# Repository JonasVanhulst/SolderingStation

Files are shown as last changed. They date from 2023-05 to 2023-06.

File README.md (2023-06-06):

# Hello, i am Jonas Vanhulst 👋

As first year electronics ICT engineer, i am very happy that i could make this nice and working soldering station.

## issues ✍️
By testing the result i found a problem while powering the opamp. The opamp didn't receive the 5V so i checked the PCB design and i found a problem with connecting the 5V to the Opamp.
So for solving this problem a singel wire was placed between the opamp and a 5V pin.

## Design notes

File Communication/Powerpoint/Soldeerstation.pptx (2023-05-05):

## Technisch ontwerp

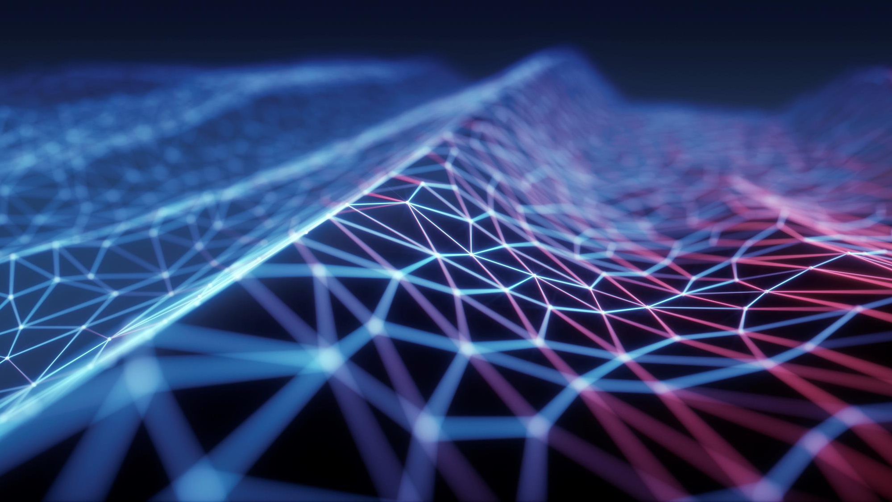
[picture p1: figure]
Digitale verbindingen

## Technische benodigdheden

SOFTWARE
COMPONENTEN
GITHUB

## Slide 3

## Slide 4

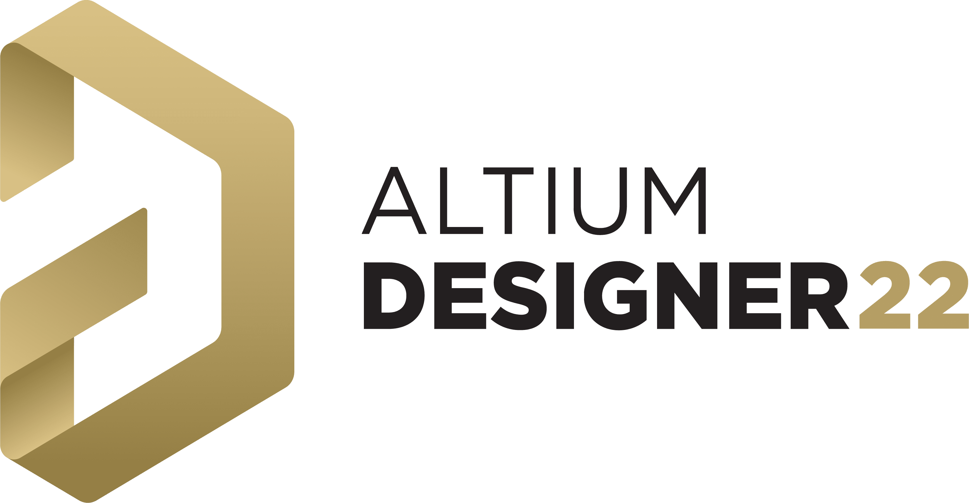
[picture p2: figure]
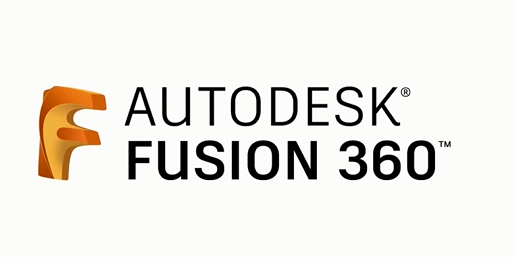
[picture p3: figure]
Fusion 360 der Einstieg – drucktipps3d.de

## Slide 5

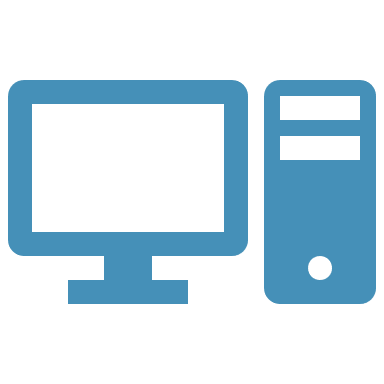
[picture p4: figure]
Computer

SOFTWARE

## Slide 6

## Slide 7

## Concurrerend landschap

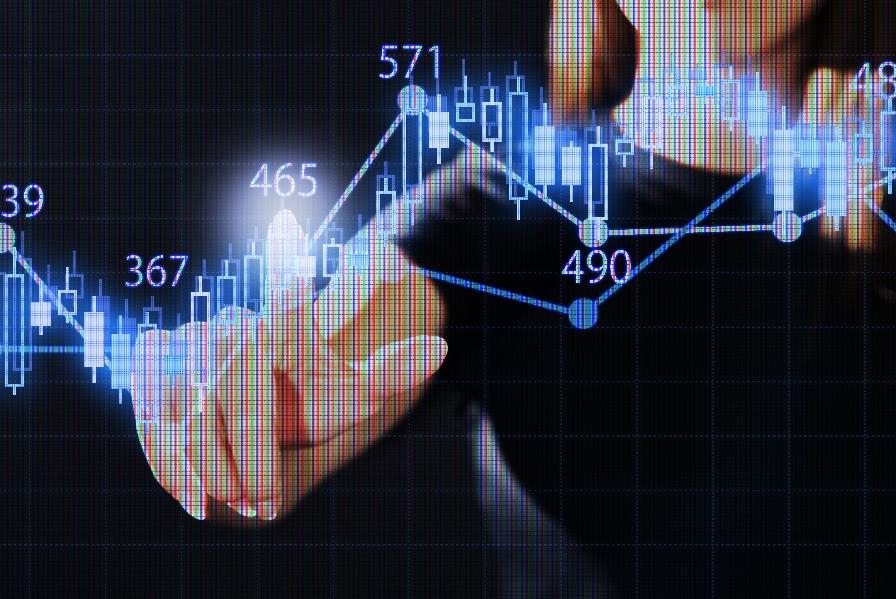
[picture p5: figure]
Grafieken
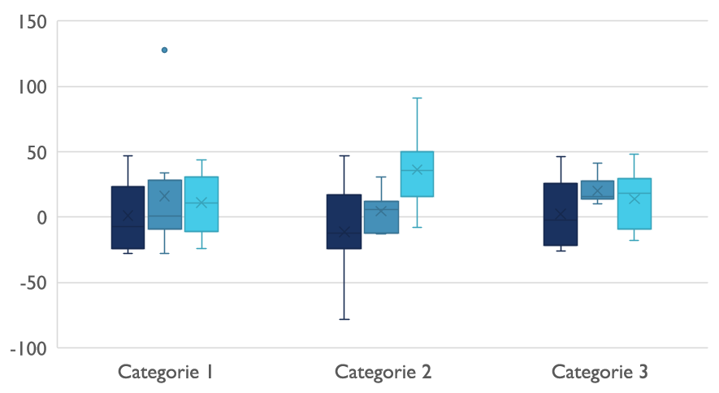
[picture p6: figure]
Tijdelijke aanduiding voor grafiek

## Digitale communicatie

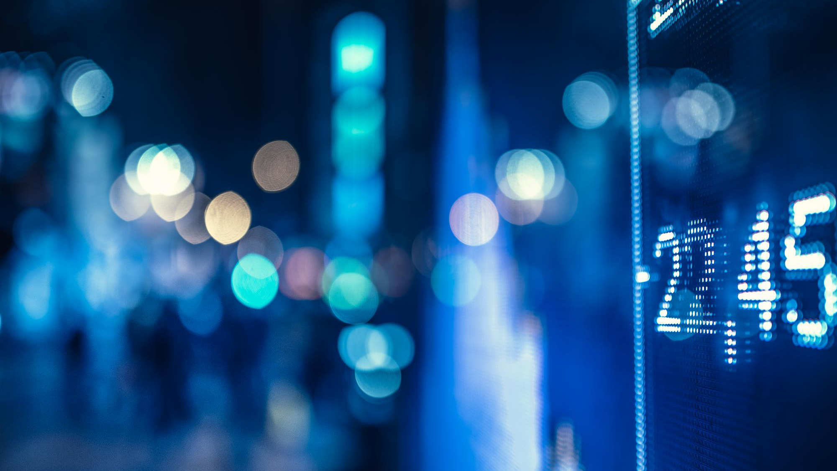
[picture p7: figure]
Digitale cijfers

Cloud
Lokaal
Hybride

## Bedankt

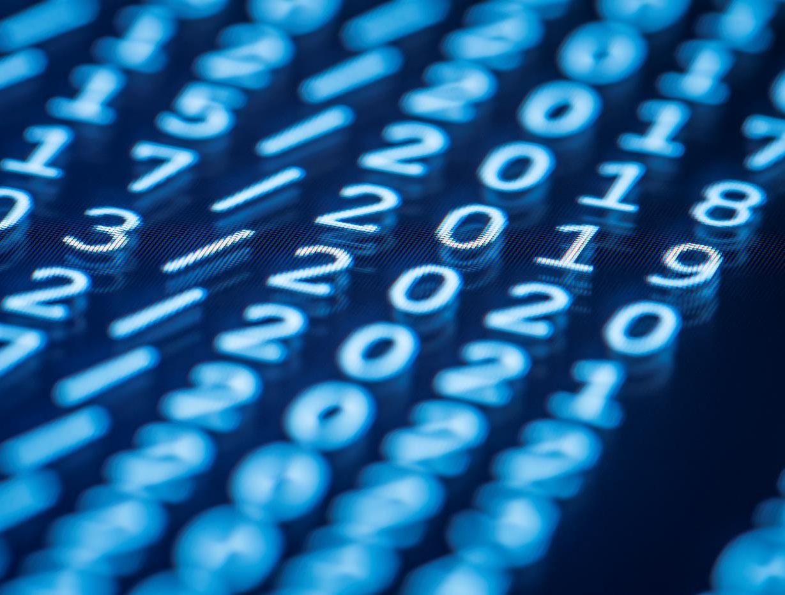
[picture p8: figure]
Digitale cijfers

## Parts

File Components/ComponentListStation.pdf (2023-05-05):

Description | Supplier

Resistor
18 kΩ | provided by PXL
1 MΩ | provided by PXL
68 kΩ | provided by PXL
5.6 kΩ, | provided by PXL
10 kΩ | provided by PXL
100 Ω | provided by PXL
10 MΩ | provided by PXL
4.7 kΩ | provided by PXL
470 Ω | provided by PXL
Inductor
Choke 10uH, 130mA | Gotron
Common mode choke 10A, Laird CM2545x171B-10 | Farnell
Capacitor
4700 µF, 50 V | Farnell
10 µF, 50 V | In stock at home
100 nF, 50 V | provided by PXL
100 µF, 50 V | Farnell
10nF, 50V | provided by PXL
Semiconductor
1N4007, 1000 V | In stock at home
Zener Single Diode, 5.1 V, 500 mW | Farnell
1N4148, 100 V, 200 mA | Farnell
Bridge rectifier D6KB6U, 600V, 6A | Farnell
BC547C, 45 V, 100 mA, 500 mW, hfe=400 | In stock at home
IRF9Z34NPBF, MOSFET-P, 55V, 17A, 100mOhm | Farnell
BC557C, -45 V, -100 mA, 500 mW, hfe=400 | In stock at home
DC/DC converter OKI-78SR-5/1.5-W36-C, 5V, 1.5A | RS components
Dual OPAMP MCP6002-E/P | Farnell
8-bit MCU ATmega4809-PF | Farnell
Other
Power Relay, 5 VDC, DPDT, 8A, Schrack RT424005 | Farnell
Terminal block | In stock at home
Pin header | provided by PXL
Pin header | provided by PXL
Pin header | provided by PXL
Pin header | provided by PXL
Pin header | provided by PXL
8 pin dip socket | In stock at home
20 pin dip socket | Gotron
40 pin dip socket | Gotron
10-way boxheader | Farnell
10 pin connector | provided by PXL
Misc.
Toroidal mains transformer 60VA, 2x115V, 2x12V, MCTA060/12 | TME
primary fuse 20mm 630mA @240VAC | Farnell
IEC connector | Amazon

## BOM:Soldering Station

10-way IDC Receptable | Fanell
10-aderige flatcable | Gotron
Encoder with pushbutton, Bourns PEC11R-4225F-N0024 | Farnell
Display
4 digit 7-segment LED display KW4-801AVB | TME
I2C LED drive control special circuit TM1637 | Amazon

Reference | Qnt | Delivery date
253 | Always available 1 | Always available 1 | Always available 4 | Always available 6 | Always available 2 | Always available 1 | Always available 6 | Always available 1 | Always available 2

78F100J-RC
1 | | | | | | | | | | | next day
CM2545X171B-10
1 | | | | | | | | | | | 19/03/2023
17
MCGPR50V478M22X41
1 | | | | | | | | | | | 19/03/2023
MCGPR50V106M5X11
3 | | | | | | | | | | | Always available
MCRR50104X7RK0050
6 | | | | | | | | | | | Always available
MCGPR50V107M8X11
2 | | | | | | | | | | | 19/03/2023
SR215C103KAR
5 | | | | | | | | | | | Always available
13
1N4007
1 | | | | | | | | | | | Always available
1N5231B+
1 | | | | | | | | | | | 19/03/2023
1N4148T
1 | | | | | | | | | | | 19/03/2023
D6KB6U
2 | | | | | | | | | | | 19/03/2023
BC547CG
3 | | | | | | | | | | | Always available
IRF9Z34NPBF
1 | | | | | | | | | | | 19/03/2023
BC557CZL1G
1 | | | | | | | | | | | Always available
OKI-78SR-5/1.5-W36-C
1 | | | | | | | | | | | 18/03/2023
MCP6002-E/P
1 | | | | | | | | | | | 19/03/2023
ATMEGA4809-PF
1 | | | | | | | | | | | 19/03/2023
21
RT424005
1 | | | | | | | | | | | 19/03/2023
MKDSN 1,5/2-5,08
4 | Always available 3 | Always available 1 | Always available 1 | Always available 1 | Always available 1 | Always available 1 | Always available 1 | next day 1 | next day 5 | 19/03/2023 1 | Always available

24
MCTA060/12
1 | 17/03/2023
10
59JR101-1FR-LR
1 | 15/03/2023

MC-254-10-00-00-IDC | 101 | next day 1 | 19/03/2023 61 | 17/03/2023 5 | 22/03/2023

Package Qnt | prices
25 | € 0,00000
3 | € ,000
1 | € ,000
1 | € ,000
4 | € ,000
6 | € ,000
2 | € ,000
1 | € ,000
6 | € ,000
1 | € ,000
2 | € 2,15000
1 | € ,5000
1 | € 1,65000
17 | € 2,92800
1 | € 2,66000
3 | € ,000
6 | € ,000
2 | € ,26800
5 | € ,000
24 | € 15,74000
1 | € ,000
5 | € ,49000
5 | € ,47000
5 | € 4,16000
3 | € ,000
1 | € 1,02000
1 | € ,000
1 | € 5,92000
1 | € ,75000
1 | € 2,93000
21 | € 4,77000
1 | € 3,49000
4 | € ,000
3 | € ,000
1 | € ,000
1 | € ,000
1 | € ,000
1 | € ,000
1 | € ,000
1 | € ,31000
1 | € ,5000
5 | € ,47000
1 | € ,000
24 | € 40,22000
1 | € 24,5700
10 | € 4,31000
1 | € 7,04000

10 | € 1,82000
1 | € ,88000
1 | € 1,6000
6 | € 6,26500
1 | € 1,51500
5 | € 4,75000
delivery costs | € 16,00000
BTW | € 5,00000
Total -btw | € 72,07300
Total: | € 93,07300

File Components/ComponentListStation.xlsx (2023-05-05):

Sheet: Blad1
Symbool op schema | Naam | waarde | type | footprint | aantal | link | thuisstock | nog te bestellen | Artikelnaam | Altium library
R1,R11,R12 | weerstand | 18 kohm | SMD | 805 | 3 |  |  | 3
R2 | weerstand | 1 Mohm | SMD | 805 | 1 |  |  | 1
R3 | weerstand | 68 kohm | SMD | 805 | 1 |  |  | 1
R4,R5,R13,R14 | weerstand | 5600 ohm | SMD | 805 | 4 |  |  | 4
R6,R7,R19 | weerstand | 10 kohm | SMD | 805 | 3 |  |  | 3
R8,R15,R18 | weerstand | 100 ohm | SMD | 805 | 3 |  |  | 3
R9 | weerstand | 10 Mohm | SMD | 805 | 1 |  |  | 1
R10,R16,R17,R20,R21,R22 | weerstand | 4700 ohm | SMD | 805 | 6 |  |  | 6 |  |  | VISHAY
R1,R2,R3 (LED-schema) | weerstand | 10 kohm | SMD | 805 | 3 |  |  | 3 |  |  | Yageo
L1 | smoorspoel | 10µH,130mA | THT |  | 1 |  |  | 1
L2 | common mode smoorspoel | 10A | THT |  | 1 |  |  | 1 | Laird CM2545x171B-10
C1 | condesator | 4700µA,50V | THT |  | 1 |  |  | 1
C2,C5,C10 | condesator | 10 µF , 50V | SMD | 805 | 3 |  | 3 | 0 | steek 2mm, 5x11mm
C3,C8,C9,C11,C14 | condesator | 100 nF , 50V , X7R | SMD | 805 | 5 |  |  | 5 | X7R, steek 5,08 mm
C4 | condesator | 100 µF, 50V | SMD | 805 | 1 |  |  | 1 | steek 3,5mm, 8x11mm
C6,C7,C12,C13 | condesator | 10 nF, 50V | SMD | 805 | 4 |  |  | 4 | steek 5mm, X7R
C1 (LED-schema) | condesator | 100 µF, 50V | SMD | 805 | 1 |  |  | 1 | steek 3,5mm, 8x11mm
C2 (LED-schema) | condesator | 100 nF, 50V, X7R | SMD | 805 | 1 |  |  | 1 | steek 5mm, X7R
C3,C4,C5 (LED-schema) | condesator | 10 nF, 50V, X7R | SMD | 805 | 3 |  |  | 3 | steek 5,08 mm
D1 (1N4007) | diode | 1000V , 1A |  |  | 1 |  | 1 | 0 | 1N4007
D2 | zenerdiode | 5,1V, 500 mW |  |  | 1 |  |  | 1
D3 (1N4148) | diode | 100V, 200mA, 4ns |  |  | 1 |  |  | 1 | 1N4148
B1,B2 (D6KB6U) | bruggelijkrichter | 600V, 6A |  |  | 2 |  |  | 2 | D6KB6U
T1,T2,T3 (BC547C) | transistor | 45V, 100mA, 500mW, hfe = 400 |  |  | 3 |  |  | 3 | BC547C
T3 (LED-schema) | p-mosfet | 55V, 17A, 100mohm |  |  | 1 |  |  | 1 | IRF9Z34NPBF, P-MOSFET
T5 (BC557C) | transistor | (-45V), (-100mA), 500mw, hfe = 400 |  |  | 1 |  |  | 1 | BC557C
IC1 | DC/DC converter | 5V, 1,5A |  |  | 1 |  |  | 1 | DC/DC-converter OKI-78SR-5/1.5-W36-C
IC2 | dual-opamp | - |  |  | 1 |  |  | 1 | dual-opamp MCP6002-E/P
IC3 | microcontroller | - |  |  | 1 |  |  | 1 | 8-bit MCU ATmega4809-PF
LD1 (LED-schema) | 4-cijferige-7-segment | - |  |  | 1 |  |  | 1 | 4-cijferig 7-segment LED-display KW4-801AVB (Luckylight)
IC1 (LED-schema) | I²C Led-driver | - |  |  | 1 |  |  | 1 | I2C LED-driver TM1637
RE1 | vermogensrelais | 5VDC, DPDT, 8A |  |  | 1 |  |  | 1 | Schrack RT424005
K1,K2,K3,K8 | printkroonsteen | 2-polig, 630V |  |  | 4 |  |  | 4 | printkroonsteen 5,08mm, 2polig
K4,K7,K10 | pinheader | 1rij, 3polig |  |  | 3 |  |  | 3 | pinheader, 1 rijig, 3-polig, verticaal
K5 | pinheader | 1rij, 2polig |  |  | 1 |  | 1 | 0 | pinheader, 1 rijig, 2-polig, verticaal
K6 | pinheader | 1rij, 4polig |  |  | 1 |  |  | 1 | pinheader, 1 rijig, 4-plig, verticaal
K9 | pinheader | 1rij, 5polig |  |  | 1 |  |  | 1 | pinheader, 1 rijig, 5-polig, verticaal
K11 | pinheader | 2rij, 6polig |  |  | 1 |  |  | 1 | pinheader, 2-rijig, 6-polig, verticaal
K12 | boxheader | 10-polig |  |  | 1 |  |  | 1 | 10-polige boxheader, steek 2,54 mm
 | ringkerntransformator | 60VA, 2x115V, 2x12V |  |  | 1 |  |  | 1 | MCTA060/12
 | primaire zekering | 630mA @ 240VAC |  |  | 1 |  |  | 1 | 20mm
 | primaire zekering | 1,25 1 @ 115VAC |  |  | 1 |  |  | 1 | 20mm
 | IEC-connector |  |  |  |  |  |  | 0 | K&B 59JR101-1FR-LR IEC-connector 42R-serie (netentree, Conrad 736709)
 | stekker | 10-polige IDC-stekker |  |  | 2 |  |  | 2 | 10-polige IDC-stekker (2 stuks)
 | flatcable | 10-aderige |  |  | 1 |  |  | 1 | 10-aderige flatcable, ca. 20 cm
 | print |  |  |  | 1 |  |  | 1 | Print 190409-1 V1.1
ENC1 | draai-encoder met drukknop |  |  |  | 1 |  |  | 1 | Bourns PEC11R-4225F-N0024
K1 (LED-schema) | 10-polige boxheader |  |  |  | 1 |  |  | 1 | K1 = 10-polige boxheader, steek 2,54 mm
 | print |  |  |  | 1 |  |  | 1 | Print 190409-2 V1.1

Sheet: Main-Print
BOM::190409-1::v1.0::Soldering Station V1.0 |  |  |  |  |  |  |  |  | copy colom J - past value only
Description | Manufacturer | Reference | Footprint | Designation | Qnt | Farnell | Bestelling | BOMformul | BOM for editors
Resistor |  |  |  |  | 21 |  |  | Resistor | Resistor
18 kΩ, carbon film, 5%, 0.25W, 250V | Multicomp | MCF 0.25W 18K | res10e | R1,R11,R12 | 3 | 9339256 | SCHOOL | R1,R11,R12 = 18 kΩ, carbon film, 5%, 0.25W, 250V | R1,R11,R12 = 18 kΩ, carbon film, 5%, 0.25W, 250V | €0.010 | €0.030
1 MΩ, carbon film, 5%, 0.25W, 250V | Multicomp | MCF 0.25W 1M | res10e | R2 | 1 | 9339086 | SCHOOL | R2 = 1 MΩ, carbon film, 5%, 0.25W, 250V | R2 = 1 MΩ, carbon film, 5%, 0.25W, 250V | €0.010 | €0.010
68 kΩ, carbon film, 5%, 0.25W, 250V | Multicomp | MCF 0.25W 68K | res10e | R3 | 1 | 9339671 | SCHOOL | R3 = 68 kΩ, carbon film, 5%, 0.25W, 250V | R3 = 68 kΩ, carbon film, 5%, 0.25W, 250V | €0.010 | €0.010
5.6 kΩ, carbon film, 5%, 0.25W, 250V | Multicomp | MCF 0.25W 5K6 | res10e | R4,R5,R13,R14 | 4 | 9339604 | SCHOOL | R4,R5,R13,R14 = 5.6 kΩ, carbon film, 5%, 0.25W, 250V | R4,R5,R13,R14 = 5.6 kΩ, carbon film, 5%, 0.25W, 250V | €0.010 | €0.040
10 kΩ, carbon film, 5%, 0.25W, 250V | Multicomp | MCF 0.25W 10K | res10e | R6,R7,R19 | 3 | 9339132 | SCHOOL | R6,R7,R19 = 10 kΩ, carbon film, 5%, 0.25W, 250V | R6,R7,R19 = 10 kΩ, carbon film, 5%, 0.25W, 250V | €0.010 | €0.030
100 Ω, carbon film, 5%, 0.25W, 250V | Multicomp | MCF 0.25W 100R | res10e | R8,R15 | 2 | 9339043 | SCHOOL | R8,R15 = 100 Ω, carbon film, 5%, 0.25W, 250V | R8,R15 = 100 Ω, carbon film, 5%, 0.25W, 250V | €0.010 | €0.020
10 MΩ, carbon film, 5%, 0.25W, 250V | Multicomp | MCF 0.25W 10M | res10e | R9 | 1 | 1186248 | SCHOOL | R9 = 10 MΩ, carbon film, 5%, 0.25W, 250V | R9 = 10 MΩ, carbon film, 5%, 0.25W, 250V | €0.010 | €0.010
4.7 kΩ, carbon film, 5%, 0.25W, 250V | Multicomp | MCF 0.25W 4K7 | res10e | R10,R16,R17,R20,R21,R22 | 6 | 9339540 | SCHOOL | R10,R16,R17,R20,R21,R22 = 4.7 kΩ, carbon film, 5%, 0.25W, 250V | R10,R16,R17,R20,R21,R22 = 4.7 kΩ, carbon film, 5%, 0.25W, 250V | €0.010 | €0.060
470 Ω, metal film, 5%, 2W, 500V | Vishay | PR02000204700JR500 | res20e | R18 | 1 | 4983828 | SCHOOL | R18 = 470 Ω, metal film, 5%, 2W, 500V | R18 = 470 Ω, metal film, 5%, 2W, 500V
Inductor |  |  |  |  | 2 |  |  | Inductor | Inductor
Choke 10uH, 130mA | Bourns | 78F100J-RC | res12e | L1 | 1 | 2333630 | 78F100J-RC - Bourns - RF Choke, RF Choke, 78F (farnell.com) (https://be.farnell.com/bourns/78f100j-rc/inductor-10uh-5-0-37a-axial/dp/2333630?ost=2333630) | L1 = Choke 10uH, 130mA | L1 = Choke 10uH, 130mA | €0.130 | €0.130
Common mode choke 10A, Laird CM2545x171B-10 | Laird | CM2545X171B-10 |  | L2 | 1 | 2292313 | CM2545X171B-10 - Laird - Choke, Common Mode, 10 A (farnell.com) (https://be.farnell.com/laird-technologies/cm2545x171b-10/choke-common-100mhz-170r/dp/2292313?ost=2292313) | L2 = Common mode choke 10A, Laird CM2545x171B-10 | L2 = Common mode choke 10A, Laird CM2545x171B-10 | €0.750 | €0.750
Capacitor |  |  |  |  | 14 |  |  | Capacitor | Capacitor
4700 µF, 50 V, 10 mm pitch, 22x41 mm | Multicomp | MCGPR50V478M22X41 | ELPP-CP-1000-2200 | C1 | 1 | 1902903 | MCGPR50V478M22X41 - Multicomp Pro - Electrolytic Capacitor, 4700 µF, 50 V (farnell.com) (https://be.farnell.com/multicomp/mcgpr50v478m22x41/cap-4700-f-50v-20/dp/1902903?ost=1902903) | C1 = 4700 µF, 50 V, 10 mm pitch, 22x41 mm | C1 = 4700 µF, 50 V, 10 mm pitch, 22x41 mm | €1.030 | €1.030
10 µF, 50 V, 2 mm pitch, 5x11 mm | Multicomp | MCGPR50V106M5X11 | elco2er | C2,C5,C10 | 3 | 9451382 | THUIS | C2,C5,C10 = 10 µF, 50 V, 2 mm pitch, 5x11 mm | C2,C5,C10 = 10 µF, 50 V, 2 mm pitch, 5x11 mm | €0.030 | €0.090
100 nF, 50 V, X7R, 5.08 mm pitch | Multicomp | MCRR50104X7RK0050 | ker1e | C3,C8,C9,C11,C14 | 5 | 1216440 | SCHOOL | C3,C8,C9,C11,C14 = 100 nF, 50 V, X7R, 5.08 mm pitch | C3,C8,C9,C11,C14 = 100 nF, 50 V, X7R, 5.08 mm pitch | €0.120 | €0.600
100 µF, 50 V, 3.5 mm pitch, 8x11 mm | Multicomp | MCGPR50V107M8X11 | ELPP-CP-350-800 | C4 | 1 | 9451412 | MCGPR50V107M8X11 - Multicomp Pro - Electrolytic Capacitor, 100 µF, 50 V (farnell.com) (https://be.farnell.com/multicomp/mcgpr50v107m8x11/cap-100-f-50v-20/dp/9451412?ost=9451412) | C4 = 100 µF, 50 V, 3.5 mm pitch, 8x11 mm | C4 = 100 µF, 50 V, 3.5 mm pitch, 8x11 mm | €0.070 | €0.070
10nF, 50V, 5mm pitch, X7R | AVX | SR215C103KAR | ker1e | C6,C7,C12,C13 | 4 | 1100389 | SCHOOL | C6,C7,C12,C13 = 10nF, 50V, 5mm pitch, X7R | C6,C7,C12,C13 = 10nF, 50V, 5mm pitch, X7R | €0.100 | €0.400
Semiconductor |  |  |  |  | 14 |  |  | Semiconductor | Semiconductor
1N4007, 1000 V, 1 A | Fairchild Semiconductor | 1N4007 | ELPP-DO-41 | D1 | 1 | 1467514 | THUIS | D1 = 1N4007, 1000 V, 1 A | D1 = 1N4007, 1000 V, 1 A | €0.050 | €0.050
Zener Single Diode, 5.1 V, 500 mW | Multicomp Pro | 1N5231B+ | diode1e | D2 | 1 | 2748145 | 1N5231B+ - Multicomp Pro - Zener Single Diode, 5.1 V, 500 mW (farnell.com) (https://be.farnell.com/multicomp/1n5231b/zener-diode-0-5w-5-1v-do-35/dp/2748145?ost=2748145) | D2 = Zener Single Diode, 5.1 V, 500 mW | D2 = Zener Single Diode, 5.1 V, 500 mW | €0.040 | €0.040
1N4148, 100 V, 200 mA, 4 ns | NXP | 1N4148 | ELPP-DO-35-x | D3 | 1 | 1081177 | 1N4148TA - Onsemi - Small Signal Diode, Single, 100 V (farnell.com) (https://be.farnell.com/on-semiconductor/1n4148ta/diode-ultrafast-300ma-100v-do/dp/2322485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) | D3 = 1N4148, 100 V, 200 mA, 4 ns | D3 = 1N4148, 100 V, 200 mA, 4 ns | €0.020 | €0.020
Zener Single Diode, 15 V, 1300 mW | Vishay | BZX85B15-TR | ELPP-DO-35-x | D4 | 1 | 2690058 | NIET NODIG | D4 = Zener Single Diode, 15 V, 1300 mW | D4 = Zener Single Diode, 15 V, 1300 mW
Bridge rectifier D6KB6U, 600V, 6A | Multicomp Pro | D6KB6U |  | B1,B2 | 2 | 2750898 | D6KB6U - Multicomp Pro - Bridge Rectifier, Single Phase, 600 V (farnell.com) (https://be.farnell.com/multicomp/d6kb6u/diode-bridge-rect-1-ph-6a-600v/dp/2750898?ost=2750898) | B1,B2 = Bridge rectifier D6KB6U, 600V, 6A | B1,B2 = Bridge rectifier D6KB6U, 600V, 6A | €0.520 | €1.040
BC547C, 45 V, 100 mA, 500 mW, hfe=400 | ON Semiconductor | BC547CG | ELPP-TO-92 | T1,T2,T4 | 3 | 2101811 | FOUT VERMOGEN | T1,T2,T4 = BC547C, 45 V, 100 mA, 500 mW, hfe=400 | T1,T2,T4 = BC547C, 45 V, 100 mA, 500 mW, hfe=400 | €0.070 | €0.210
IRF9Z34NPBF, MOSFET-P, 55V, 17A, 100mOhm | Infineon | IRF9Z34NPBF | TO-92 | T3 | 1 | 8648689 | IRF9Z34NPBF - Infineon - Power MOSFET, P Channel, 55 V (farnell.com) (https://be.farnell.com/infineon/irf9z34npbf/mosfet-p-55v-17a-to-220/dp/8648689?ost=8648689) | T3 = IRF9Z34NPBF, MOSFET-P, 55V, 17A, 100mOhm | T3 = IRF9Z34NPBF, MOSFET-P, 55V, 17A, 100mOhm | €0.520 | €0.520
BC557C, -45 V, -100 mA, 500 mW, hfe=400 | ON Semiconductor | BC557CZL1G | ELPP-TO-92 | T5 | 1 | 2317549 | FOUT VERMOGEN | T5 = BC557C, -45 V, -100 mA, 500 mW, hfe=400 | T5 = BC557C, -45 V, -100 mA, 500 mW, hfe=400 | €0.070 | €0.070
DC/DC converter OKI-78SR-5/1.5-W36-C, 5V, 1.5A | Murata | OKI-78SR-5/1.5-W36-C |  | IC1 | 1 | 2102101 | OKI-78SR-5/1.5-W36-C Murata Power Solutions - Converter: DC/DC | 7,5W; Uin: 7÷36V; Uuit: 5VDC; Iuit: 1,5A; 500kHz; OKI78SR-5/1.5-W36C | TME - Elektronische Componenten (https://www.tme.eu/be/nl/details/oki78sr-5_1.5-w36c/dc-dc-converters/murata-power-solutions/oki-78sr-5-1-5-w36-c/) | IC1 = DC/DC converter OKI-78SR-5/1.5-W36-C, 5V, 1.5A | IC1 = DC/DC converter OKI-78SR-5/1.5-W36-C, 5V, 1.5A | €3.610 | €3.610
Dual OPAMP MCP6002-E/P | Microchip | MCP6002-E/P | dip8e | IC2 | 1 | 1332117 | MCP6002-E/P - Microchip - Operational Amplifier, Dual, 2 Amplifier (farnell.com) (https://be.farnell.com/microchip/mcp6002-e-p/ic-op-amp-dual-1mhz-dip8-6002/dp/1332117?ost=1332117) | IC2 = Dual OPAMP MCP6002-E/P | IC2 = Dual OPAMP MCP6002-E/P | €0.240 | €0.240
8-bit MCU ATmega4809-PF | Microchip | ATMEGA4809-PF | dip40e | IC3 | 1 | 3130179 | ATMEGA4809-PF - Microchip - 8 Bit MCU, AVR Family ATmega4809 Series Microcontrollers, 20 MHz (farnell.com) (https://be.farnell.com/microchip/atmega4809-pf/mcu-8bit-20mhz-dip-40/dp/3130179?ost=3130179) | IC3 = 8-bit MCU ATmega4809-PF | IC3 = 8-bit MCU ATmega4809-PF | €1.690 | €1.690
Other |  |  |  |  | 20 |  |  | Other | Other
Power Relay, 5 VDC, DPDT, 8A, Schrack RT424005 | Schrack | RT424005 |  | RE1 | 1 | 1629052 | 5-1393243-9 - Schrack - Te Connectivity - General Purpose Relay, RT2 Series, Power (farnell.com) (https://be.farnell.com/schrack-te-connectivity/rt424005/relay-dpdt-250vac-8a/dp/1629052?st=1629052) | RE1 = Power Relay, 5 VDC, DPDT, 8A, Schrack RT424005 | RE1 = Power Relay, 5 VDC, DPDT, 8A, Schrack RT424005 | €2.200 | €2.200
Terminal block 5.08 mm, 2-way, 630 V | Phoenix Contact | MKDSN 1,5/2-5,08 | 2-connect-2 | K1,K2,K3,K8 | 4 | 3041440 | gotron | K1,K2,K3,K8 = Terminal block 5.08 mm, 2-way, 630 V | K1,K2,K3,K8 = Terminal block 5.08 mm, 2-way, 630 V | €0.860 | €3.440
Pin header, breakable, 1 row, 3-way, vertical | TE Connectivity | 4-103321-8 | sil3e | K4,K7,K10 | 3 | 1098454 | SCHOOL | K4,K7,K10 = Pin header, breakable, 1 row, 3-way, vertical | K4,K7,K10 = Pin header, breakable, 1 row, 3-way, vertical | €0.040 | €0.120
Pin header, breakable, 1 row, 2-way, vertical | TE Connectivity | 4-103321-8 | sil2e | K5 | 1 | 1098454 | SCHOOL | K5 = Pin header, breakable, 1 row, 2-way, vertical | K5 = Pin header, breakable, 1 row, 2-way, vertical | €0.030 | €0.030
Pin header, breakable, 1 row, 4-way, vertical | TE Connectivity | 4-103321-8 | sil4e | K6 | 1 | 1098454 | SCHOOL | K6 = Pin header, breakable, 1 row, 4-way, vertical | K6 = Pin header, breakable, 1 row, 4-way, vertical | €0.040 | €0.040
Pin header, breakable, 1 row, 5-way, vertical | TE Connectivity | 4-103321-8 | sil5e | K9 | 1 | 1098454 | SCHOOL | K9 = Pin header, breakable, 1 row, 5-way, vertical | K9 = Pin header, breakable, 1 row, 5-way, vertical | €0.050 | €0.050
Pin header, breakable, 2 rows, 6-way, vertical | TE Connectivity | 4-103322-2 |  | K11 | 1 | 1098460 | SCHOOL | K11 = Pin header, breakable, 2 rows, 6-way, vertical | K11 = Pin header, breakable, 2 rows, 6-way, vertical | €0.050 | €0.050
10-way boxheader, pitch 2.54mm | Multicomp Pro | MC-254-10-00-ST-DIP |  | K12 | 1 | 2843527 | MC-254-10-00-ST-DIP - Multicomp Pro - Pin Header, Wire-to-Board, 2.54 mm (farnell.com) (https://be.farnell.com/multicomp/mc-254-10-00-st-dip/connector-header-10pos-2row-2/dp/2843527?ost=2843527) | K12 = 10-way boxheader, pitch 2.54mm | K12 = 10-way boxheader, pitch 2.54mm | €0.120 | €0.120
 |  |  |  |  |  |  |  |  | 0
Misc. |  |  |  |  |  |  |  | Misc. | Misc.
Toroidal mains transformer 60VA, 2x115V, 2x12V, MCTA060/12 | Multicomp | MCTA060/12 |  |  | 1 | 9530428 | TST 60/002 INDEL - Transformator: ringkern | 60VA; 230VAC; 12V; 12V; 2,5A; 2,5A; 0,8kg; TST60W/2X12V | TME - Elektronische Componenten (https://www.tme.eu/be/nl/details/tst60w_2x12v/toroidale-transformatoren/indel/tst-60-002/) | Toroidal mains transformer 60VA, 2x115V, 2x12V, MCTA060/12 | Toroidal mains transformer 60VA, 2x115V, 2x12V, MCTA060/12 | €20.000 | €20.000
primary fuse 20mm 630mA @240VAC |  |  |  |  | 1 |  | 0034.3115 - Schurter - Fuse, Cartridge, Time Delay (farnell.com) (https://be.farnell.com/schurter/0034-3115/fuse-antisurge-glass-fst-t630mal250v/dp/1360808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) | primary fuse 20mm 630mA @240VAC | primary fuse 20mm 630mA @240VAC |  | €0.000
primary fuse 20mm 1.25A @115VAC |  |  |  |  | 1 |  |  | primary fuse 20mm 1.25A @115VAC | primary fuse 20mm 1.25A @115VAC |  | €0.000
K & B 59JR101-1FR-LR IEC connector 42R Series (mains connectors) 42R Plug, vertical mount Total number of pins: 2 + PE 1 | K & B | 59JR101-1FR-LR |  |  | 1 |  | 736709 | K & B 59JR101-1FR-LR IEC connector 42R Series (mains connectors) 42R Plug, vertical mount Total number of pins: 2 + PE 1 | K & B 59JR101-1FR-LR IEC connector 42R Series (mains connectors) 42R Plug, vertical mount Total number of pins: 2 + PE 1 | €8.790 | €8.790
10-way IDC Receptable | Multicomp | MC-254-10-00-00-IDC |  |  | 2 | 2843495 | MC-254-10-00-00-IDC - Multicomp Pro - IDC Connector, IDC Receptacle, Female (farnell.com) (https://be.farnell.com/multicomp/mc-254-10-00-00-idc/connector-rcpt-10pos-2row-2-54mm/dp/2843495?ost=2843495) | 10-way IDC Receptable | 10-way IDC Receptable | €0.300 | €0.600
PCB 190409-1 V1.2 |  |  |  |  | 1 |  |  | PCB 190409-1 V1.2 | PCB 190409-1 V1.2 | €1.500 | €1.500
10-aderige flatcable |  |  |  |  |  |  |  |  |  | TOTAL: | €47.710
 |  | Prices: 100+ Farnell (unless otherwise stated)
LEGENDE
 | SCHOOL
 | OVERBODIG
 | IN BESTELLING bij Farnell/TME
 | AMAZON
 | GOTRON
 | THUIS

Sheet: BOM
BOM:Soldering Station
Description | Supplier | Reference | Qnt | Delivery date | Package Qnt | prices
Resistor |  |  | 25 |  | 25 | €0.00000
18 kΩ | provided by PXL |  | 3 | Always available | 3 | €0.000
1 MΩ | provided by PXL |  | 1 | Always available | 1 | €0.000
68 kΩ | provided by PXL |  | 1 | Always available | 1 | €0.000
5.6 kΩ, | provided by PXL |  | 4 | Always available | 4 | €0.000
10 kΩ | provided by PXL |  | 6 | Always available | 6 | €0.000
100 Ω | provided by PXL |  | 2 | Always available | 2 | €0.000
10 MΩ | provided by PXL |  | 1 | Always available | 1 | €0.000
4.7 kΩ | provided by PXL |  | 6 | Always available | 6 | €0.000
470 Ω | provided by PXL |  | 1 | Always available | 1 | €0.000
Inductor |  |  | 2 |  | 2 | €2.15000
Choke 10uH, 130mA | Gotron | 78F100J-RC | 1 | next day | 1 | €0.500
Common mode choke 10A, Laird CM2545x171B-10 | Farnell | CM2545X171B-10 | 1 | 2023-03-19 | 1 | €1.650
Capacitor |  |  | 17 |  | 17 | €2.92800
4700 µF, 50 V | Farnell | MCGPR50V478M22X41 | 1 | 2023-03-19 | 1 | €2.660
10 µF, 50 V | In stock at home | MCGPR50V106M5X11 | 3 | Always available | 3 | €0.000
100 nF, 50 V | provided by PXL | MCRR50104X7RK0050 | 6 | Always available | 6 | €0.000
100 µF, 50 V | Farnell | MCGPR50V107M8X11 | 2 | 2023-03-19 | 2 | €0.268
10nF, 50V | provided by PXL | SR215C103KAR | 5 | Always available | 5 | €0.000
Semiconductor |  |  | 13 |  | 24 | €15.740
1N4007, 1000 V | In stock at home | 1N4007 | 1 | Always available | 1 | €0.000
Zener Single Diode, 5.1 V, 500 mW | Farnell | 1N5231B+ | 1 | 2023-03-19 | 5 | €0.490
1N4148, 100 V, 200 mA | Farnell | 1N4148T | 1 | 2023-03-19 | 5 | €0.470
Bridge rectifier D6KB6U, 600V, 6A | Farnell | D6KB6U | 2 | 2023-03-19 | 5 | €4.160
BC547C, 45 V, 100 mA, 500 mW, hfe=400 | In stock at home | BC547CG | 3 | Always available | 3 | €0.000
IRF9Z34NPBF, MOSFET-P, 55V, 17A, 100mOhm | Farnell | IRF9Z34NPBF | 1 | 2023-03-19 | 1 | €1.020
BC557C, -45 V, -100 mA, 500 mW, hfe=400 | In stock at home | BC557CZL1G | 1 | Always available | 1 | €0.000
DC/DC converter OKI-78SR-5/1.5-W36-C, 5V, 1.5A | RS components | OKI-78SR-5/1.5-W36-C | 1 | 2023-03-18 | 1 | €5.920
Dual OPAMP MCP6002-E/P | Farnell | MCP6002-E/P | 1 | 2023-03-19 | 1 | €0.750
8-bit MCU ATmega4809-PF | Farnell | ATMEGA4809-PF | 1 | 2023-03-19 | 1 | €2.930
Other |  |  | 21 |  | 21 | €4.77000
Power Relay, 5 VDC, DPDT, 8A, Schrack RT424005 | Farnell | RT424005 | 1 | 2023-03-19 | 1 | €3.490
Terminal block | In stock at home | MKDSN 1,5/2-5,08 | 4 | Always available | 4 | €0.000
Pin header | provided by PXL |  | 3 | Always available | 3 | €0.000
Pin header | provided by PXL |  | 1 | Always available | 1 | €0.000
Pin header | provided by PXL |  | 1 | Always available | 1 | €0.000
Pin header | provided by PXL |  | 1 | Always available | 1 | €0.000
Pin header | provided by PXL |  | 1 | Always available | 1 | €0.000
8 pin dip socket | In stock at home |  | 1 | Always available | 1 | €0.000
20 pin dip socket | Gotron |  | 1 | next day | 1 | €0.310
40 pin dip socket | Gotron |  | 1 | next day | 1 | €0.500
10-way boxheader | Farnell |  | 5 | 2023-03-19 | 5 | €0.470
10 pin connector | provided by PXL |  | 1 | Always available | 1 | €0.000
Misc. |  |  | 24 |  | 24 | €40.22000
Toroidal mains transformer 60VA, 2x115V, 2x12V, MCTA060/12 | TME | MCTA060/12 | 1 | 2023-03-17 | 1 | €24.5700
primary fuse 20mm 630mA @240VAC | Farnell |  | 10 |  | 10 | €4.310
IEC connector | Amazon | 59JR101-1FR-LR | 1 | 2023-03-15 | 1 | €7.040
10-way IDC Receptable | Fanell | MC-254-10-00-00-IDC | 10 |  | 10 | €1.820
10-aderige flatcable | Gotron |  | 1 | next day | 1 | €0.880
Encoder with pushbutton, Bourns PEC11R-4225F-N0024 | Farnell |  | 1 | 2023-03-19 | 1 | €1.600
Display |  |  | 6 |  | 6 | €6.26500
4 digit 7-segment LED display KW4-801AVB | TME |  | 1 | 2023-03-17 | 1 | €1.515
I2C LED drive control special circuit TM1637 | Amazon |  | 5 | 2023-03-22 | 5 | €4.750
 |  |  |  |  | delivery costs | €16.00000
 |  |  |  |  | BTW | €5.00000
 |  |  |  |  | Total -btw | €72.07300
 |  |  |  |  | Total: | €93.07300

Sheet: LCD-Print
BOM::190409-2::v1.1::Soldering Station |  |  |  |  |  |  |  |  |  | copy colom J - past value only
Description | Manufacturer | Reference | Footprint | Designation | Qnt | Farnell | RS | Bestelling | BOMformul | BOM for editors
Resistor |  |  |  |  | 3 |  |  |  | Resistor | Resistor
10 kΩ, carbon film, 5%, 0.25W, 250V | Multicomp | MCF 0.25W 10K | res10e | R1,R2,R3 | 3 | 9339132 |  | SCHOOL | R1,R2,R3 = 10 kΩ, carbon film, 5%, 0.25W, 250V | R1,R2,R3 = 10 kΩ, carbon film, 5%, 0.25W, 250V | €0.010 | €0.030
Inductor |  |  |  |  |  |  |  |  | Inductor | Inductor
Capacitor |  |  |  |  | 5 |  |  |  | Capacitor | Capacitor
100 µF, 50 V, 3.5 mm pitch, 8x11 mm | Multicomp | MCGPR50V107M8X11 | ELPP-CP-350-800 | C1 | 1 | 9451412 |  | MCGPR50V107M8X11 - Multicomp Pro - Electrolytic Capacitor, 100 µF, 50 V (farnell.com) (https://be.farnell.com/multicomp/mcgpr50v107m8x11/cap-100-f-50v-20/dp/9451412?ost=9451412) | C1 = 100 µF, 50 V, 3.5 mm pitch, 8x11 mm | C1 = 100 µF, 50 V, 3.5 mm pitch, 8x11 mm | €0.070 | €0.070
100 nF, 50 V, X7R, 5.08 mm pitch | Multicomp | MCRR50104X7RK0050 | ker1e | C2 | 1 | 1216440 |  | SCHOOL | C2 = 100 nF, 50 V, X7R, 5.08 mm pitch | C2 = 100 nF, 50 V, X7R, 5.08 mm pitch | €0.120 | €0.120
10nF, 50V, 5mm pitch, X7R | AVX | SR215C103KAR | ker1e | C3,C4,C5 | 4 | 1100389 |  | SCHOOL | C3,C4,C5 = 10nF, 50V, 5mm pitch, X7R | C3,C4,C5 = 10nF, 50V, 5mm pitch, X7R | €0.100 | €0.400
Semiconductor |  |  |  |  | 2 |  |  |  | Semiconductor | Semiconductor
 |  |  |  |  |  |  |  |  |  | 0
Quadruple digit 7-segment LED display KW4-801AVB (Luckylight) | Luckylight | KW4-801AVB |  | LD1 | 1 | 1467514 |  | https://www.tme.eu/be/nl/details/kw4-801avb/led-displays-viervoudig/luckylight/ | LD1 = Quadruple digit 7-segment LED display KW4-801AVB (Luckylight) | LD1 = Quadruple digit 7-segment LED display KW4-801AVB (Luckylight) | €1.500 | €1.500
I2C LED drive control special circuit TM1637 | Titan Micro Electronics | TM1637 | DIP20E | IC1 | 1 |  |  | Amazon.com.be-winkelwagen (https://www.amazon.com.be/-/nl/gp/cart/view.html?ref_=nav_cart) | IC1 = I2C LED drive control special circuit TM1637 | IC1 = I2C LED drive control special circuit TM1637 | €0.160 | €0.160
Other |  |  |  |  | 3 |  |  |  | Other | Other
Encoder with pushbutton, Bourns PEC11R-4225F-N0024 | Bourns | PEC11R-4225F-N0024 |  | ENC1 | 1 |  | 789-9557 | PEC11R-4225F-N0024 | Bourns 24 Pulse Incremental Mechanical Rotary Encoder with a 6 mm Flat Shaft (Not Indexed), Through Hole | RS (rs-online.com) (https://benl.rs-online.com/web/p/mechanical-rotary-encoders/7899557) | ENC1 = Encoder with pushbutton, Bourns PEC11R-4225F-N0024 | ENC1 = Encoder with pushbutton, Bourns PEC11R-4225F-N0024 | €1.380 | €1.380
10-way boxheader, pitch 2.54mm | Multicomp Pro | MC-254-10-00-ST-DIP |  | K1 | 1 | 2843527 |  | MC-254-10-00-ST-DIP - Multicomp Pro - Pin Header, Wire-to-Board, 2.54 mm (farnell.com) (https://be.farnell.com/multicomp/mc-254-10-00-st-dip/connector-header-10pos-2row-2/dp/2843527?ost=2843527) | K1 = 10-way boxheader, pitch 2.54mm | K1 = 10-way boxheader, pitch 2.54mm | €0.120 | €0.120
 |  |  |  |  |  |  |  |  |  | 0
Misc. |  |  |  |  |  |  |  |  | Misc. | Misc.
PCB 190409-2 V1.1 |  |  |  |  | 1 |  |  |  | PCB 190409-2 V1.1 | PCB 190409-2 V1.1 | €1.500 | €1.500
 |  |  |  |  |  |  |  |  |  |  | TOTAL: | €5.280
 |  | Prices: 100+ Farnell (unless otherwise stated)
 | SCHOOL
 | OVERBODIG
 | IN BESTELLING bij Farnell/TME
 | AMAZON
 | GOTRON

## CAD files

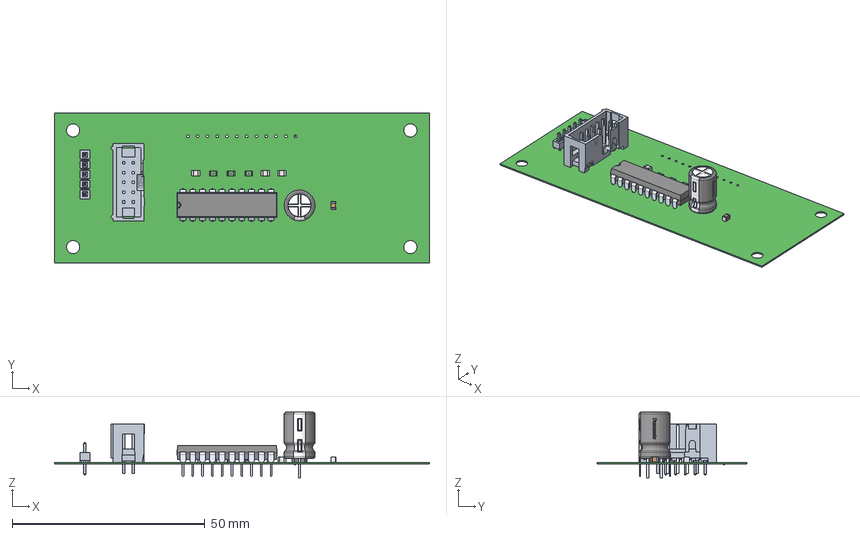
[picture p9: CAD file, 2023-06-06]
Wall_E_Case/3D_PCB/DisplayPrint.step
97.2 x 39.0 x 17.0 mm
TSW-105-05-X-S
top x 7
Vishay x 3
Extruded x 16
2510-6002-XX_STEP
Terminals
Center
Murata
marking
bottom
logo
polarity marking
terminal

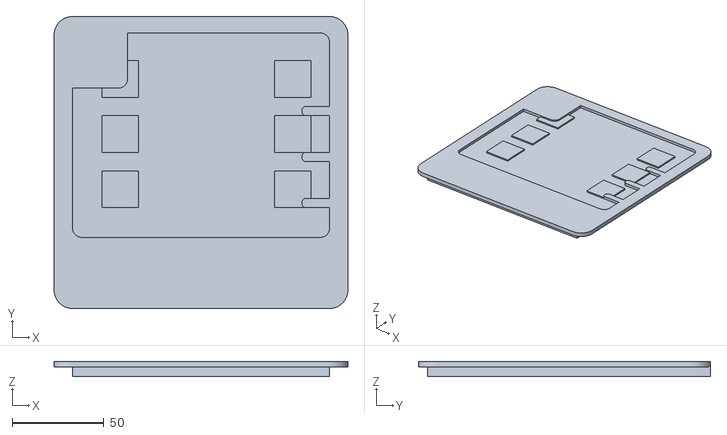
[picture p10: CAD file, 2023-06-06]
Wall_E_Case/Body/Body-Wall-E-Top.stl
160.0 x 159.0 x 8.00

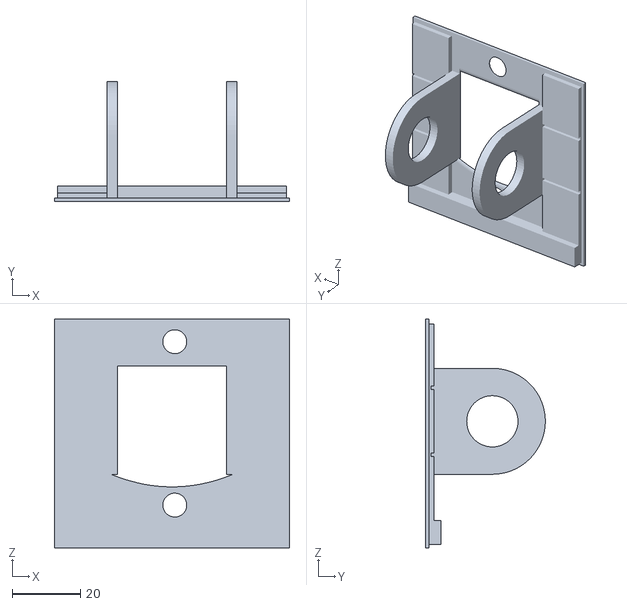
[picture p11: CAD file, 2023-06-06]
Wall_E_Case/Body/Body-Wall-E-Top-Stand.stl
68.7 x 35.0 x 66.9

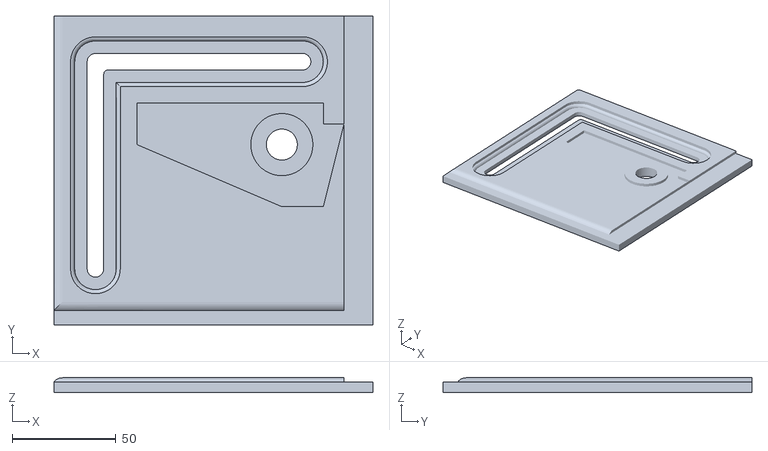
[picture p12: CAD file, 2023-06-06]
Wall_E_Case/Body/Body-Wall-E-Left.stl
154.0 x 149.0 x 7.00

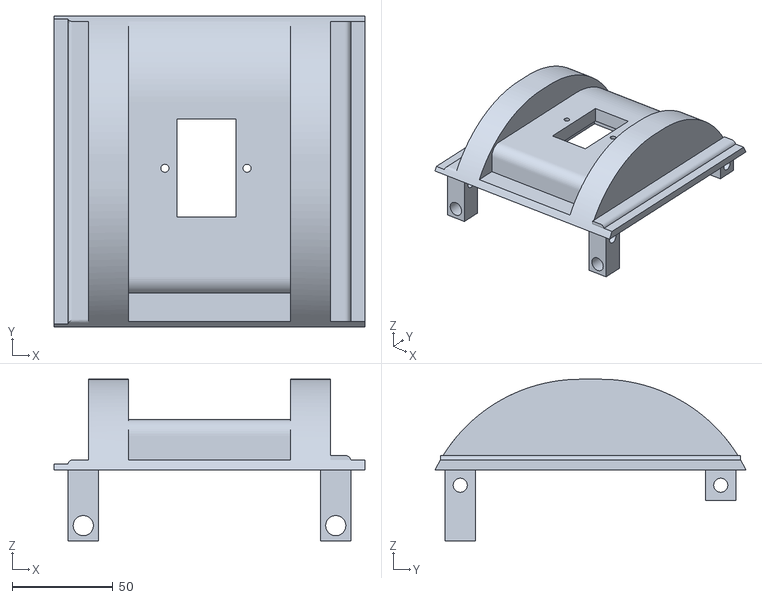
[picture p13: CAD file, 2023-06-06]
Wall_E_Case/Body/Body-Wall-E-Back.stl
154.0 x 154.0 x 80.0

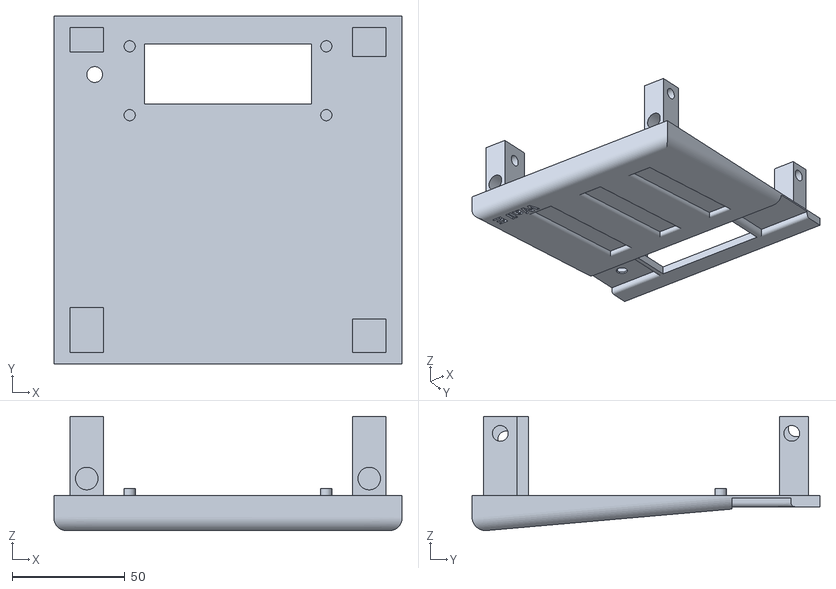
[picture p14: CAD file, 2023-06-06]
Wall_E_Case/Body/Body-Wall-E-Front.stl
154.0 x 154.0 x 50.5

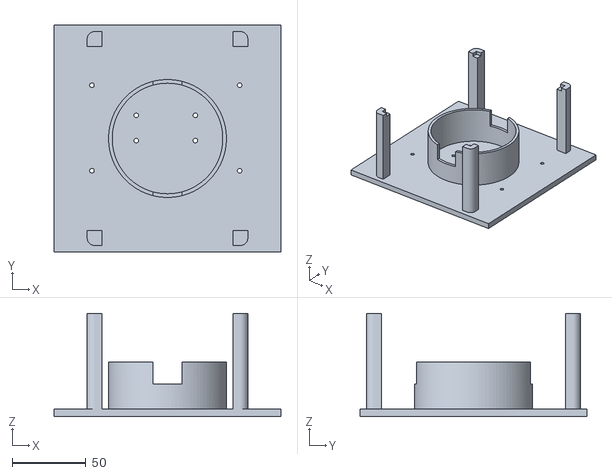
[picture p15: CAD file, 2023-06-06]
Wall_E_Case/Body/Body-Wall-E-Bottom.stl
154.0 x 154.0 x 70.0

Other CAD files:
Wall_E_Case/Body/Body-Wall-E-Right.stl
Wall_E_Case/Body/Body-Wall-E-Back Copy_.f3z
Wall_E_Case/Body/Body-Wall-E-Left v4.f3d
Wall_E_Case/Body/Body-Wall-E-Left_.f3d
Wall_E_Case/Body/Body-Wall-E-Right v11.f3d
Wall_E_Case/Body/Body-wall-E-Buttom v16.f3z
Wall_E_Case/Body/Front-Body v6.f3z
Wall_E_Case/Body/Wall-E-TOP v5.f3d
Wall_E_Case/Body/Wall_E_STANDOFF_TOP v1.f3d
Wall_E_Case/Body/body-top v5.f3d
Wall_E_Case/Body/wall-E_standoff v1.f3d

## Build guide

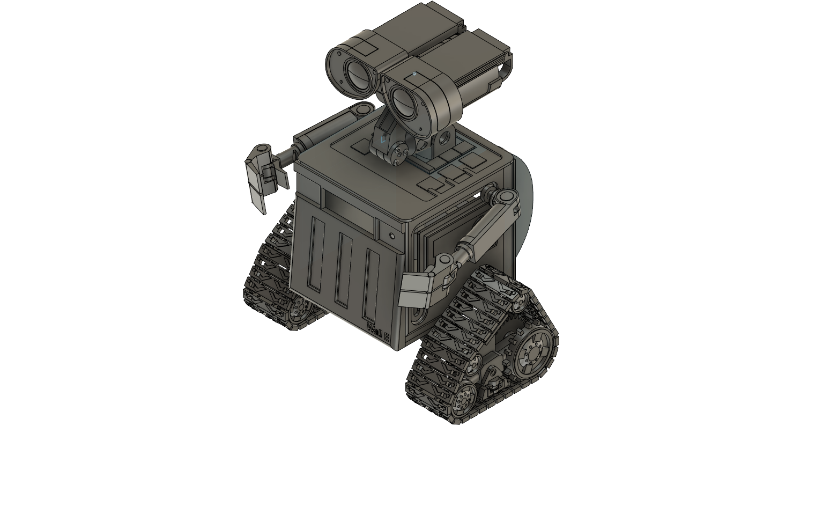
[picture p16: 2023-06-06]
Wall_E_Case/Assembly-Wall-E v25.png
